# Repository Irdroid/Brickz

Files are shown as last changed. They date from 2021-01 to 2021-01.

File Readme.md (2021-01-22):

**Brickz Bluetooth Infrared Blaster / Transmitter by Irdroid**

**Introduction** 

Brickz is a Open Source Platform Independent Bluetooth Infrared Transmitter / Blaster that supports GNU Linux, MS Windows MAC OS X and Android. Brickz allows you to transmit Pronto HEX Infrared codes via its built-in infrared LEDs or via a IR extender cable that connect to brickz via a 3.5mm Mono Audio jack. The unit is capable of connecting to the host PC via USB as well as Bluetooth. It shows up as a bluetooth serial port, when that interface option is used, or as a USB Serial Device if the USB Interface connection is used.(https://irdroid.eu/product/brickz/)
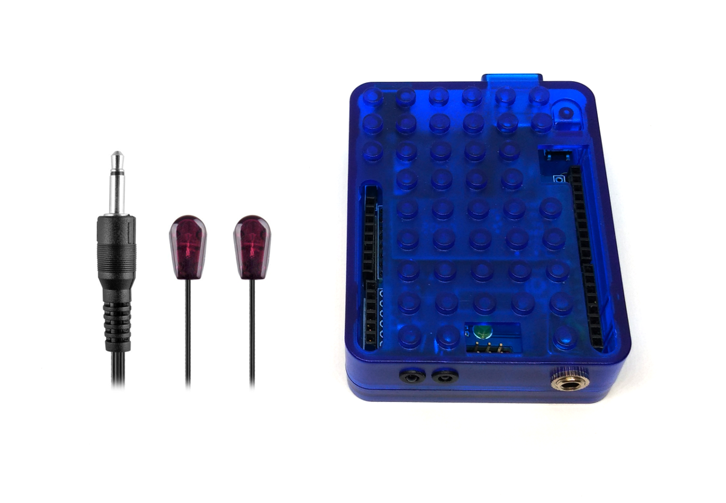
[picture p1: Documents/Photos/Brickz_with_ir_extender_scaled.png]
Brickz


**Features:**
- Bluetooth communication with the HOST SYSTEM / MCU
- USB Connection with the host System
- Built-in high power infrared leds
- Optional infrared transmitter extender
- Infrared operates at 940nm wavelength

**Example Application:**
- Digital signage infrared remote control & automation
- Home Automation & remote control
- Media remote control & automation systems

**How It works?**

Brickz listens for PRONTO HEX infrared codes via USB<>Serial or Bluetooht, simply connect to brickz via Bluetooth or USB open a terminal and type in the PRONTO code and hit enter, the command will be blasted through Brickz.If you are using Brickz with Android you can check out the example open source application that comes with brickz for sending pronto HEX codes. For detailed examples and usage, please refer to Brickz User's Manual, available in this repo.

On MAC OS X and GNU Linux once you pair with Brickz you can send PRONTO HEX codes directly from the console or via a bash script. This gives you the ability to make automation using script or controlling infrared devices directly from the console, from a script or scheduling infrared commands via cron. On MS Windows you can use any terminal application such as realterm or putty to send infrared commands with Brickz, or use the SerialSend.exe command line utility to send Infrared Codes to Brickz.

**Product website and Documentation**

- [Brickz official product Website](https://irdroid.eu/product/brickz)
- Documentation, Schematics, Production files and Software for Brickz can be found in this repository.

**Purchase sample unit**

- [Brickz official product Website](https://irdroid.eu/product/brickz)
- [Tindie](https://www.tindie.com/products/irdroid/brickz-bluetooth-infrared-transmitter/)

**You want to help with the development?**

- Write us an email to info@irdroid.com

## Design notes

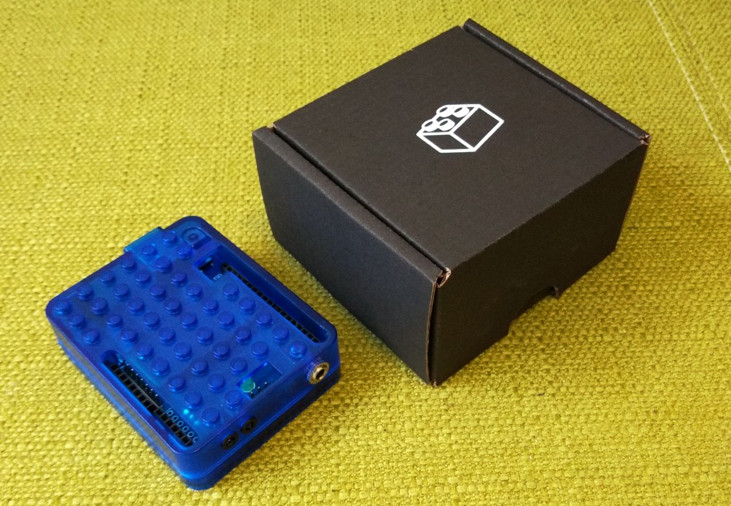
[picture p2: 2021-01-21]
Documents/Photos/Brickz_with_box_scaled.png

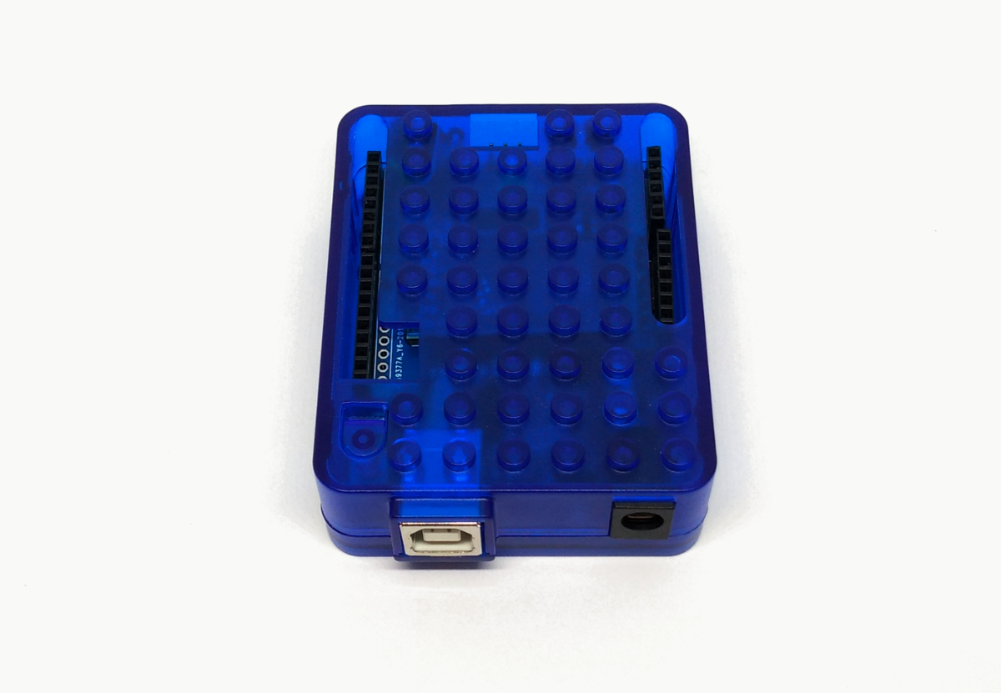
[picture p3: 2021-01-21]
Documents/Photos/Brickz_back_interfaces.png

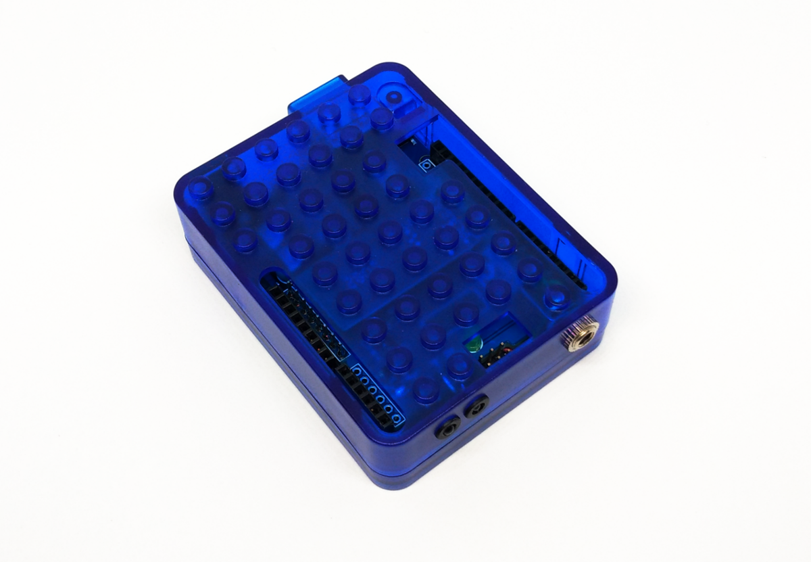
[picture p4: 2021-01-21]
Documents/Photos/Brickz_front_interfaces.png

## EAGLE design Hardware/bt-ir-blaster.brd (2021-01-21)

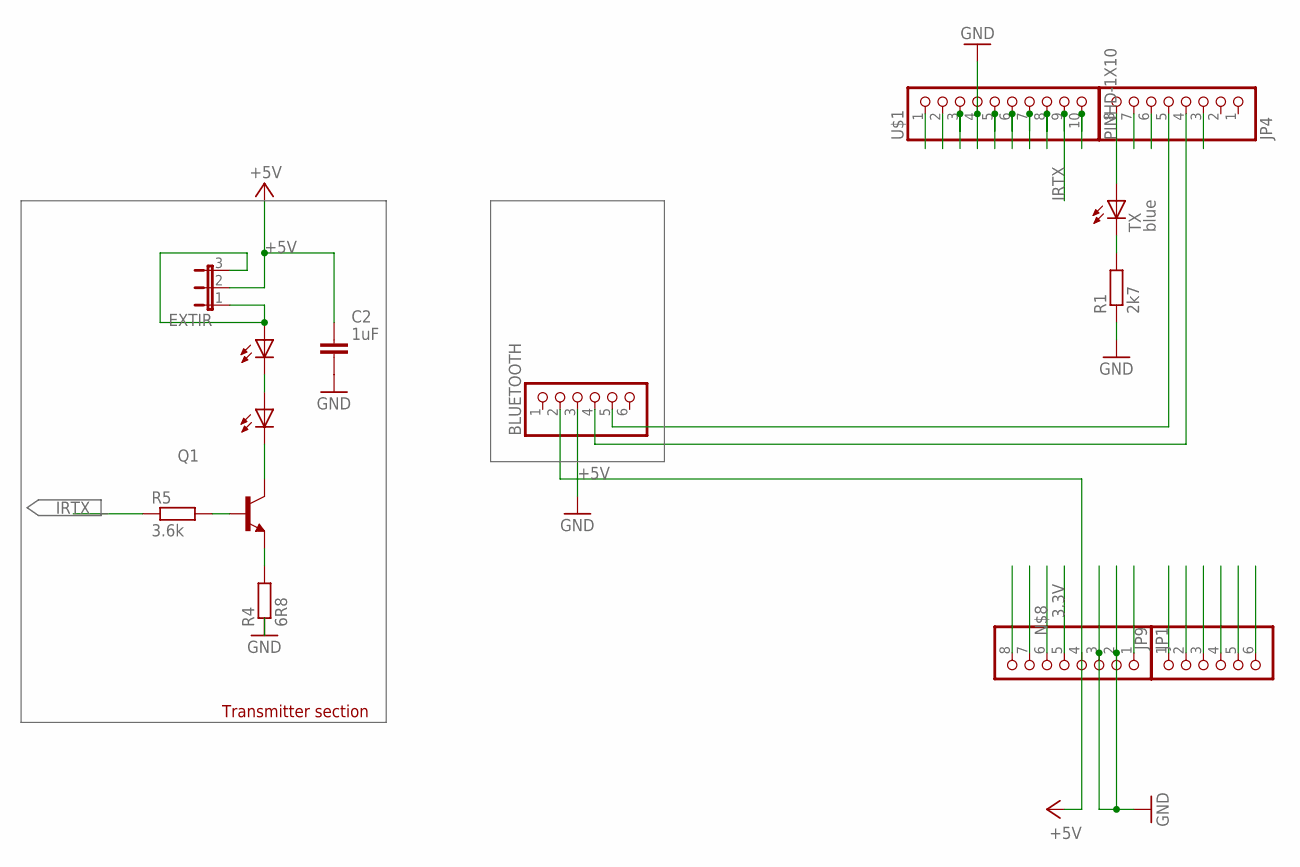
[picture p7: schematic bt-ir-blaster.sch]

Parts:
BLUETOOTH: PINHD-1X6; 1X06
C2: 1uF; C603@1
EXTIR: JP2E; JP2
JP1, JP4: PINHD-1X8BIG; 1X08-BIG
JP9: PINHD-1X6B; 1X06-BIG
Q1: TRANSISTOR_BJT_NPN-SOT-23-BCE; SOT-23
R1: 2k7; R0805
R4: 6R8; R1206
R5: 3.6k; R0603
TX: blue; LED3MM
U$1: PINHD-1X10; 1X10-BIG
U$5, U$7: IRLED5MM; IRLED_HOLDER

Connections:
3.3V: JP1.5
+5V: BLUETOOTH.2, C2.1, EXTIR.2, JP1.4
A: Q1.2 (C), U$5.K (C)
GND: BLUETOOTH.3, C2.2, JP1.2, JP1.3, R1.1, R4.1, U$1.4
IRTX: R5.1, U$1.9
K: Q1.3 (E), R4.2
unnamed: Q1.1 (B), R5.2
unnamed: U$5.A, U$7.K (C)
unnamed: R1.2, TX.K (C)
unnamed: EXTIR.1, EXTIR.3, U$7.A
unnamed: BLUETOOTH.4, JP4.4
unnamed: BLUETOOTH.5, JP4.5
unnamed: JP4.8, TX.A

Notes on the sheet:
Transmitter section

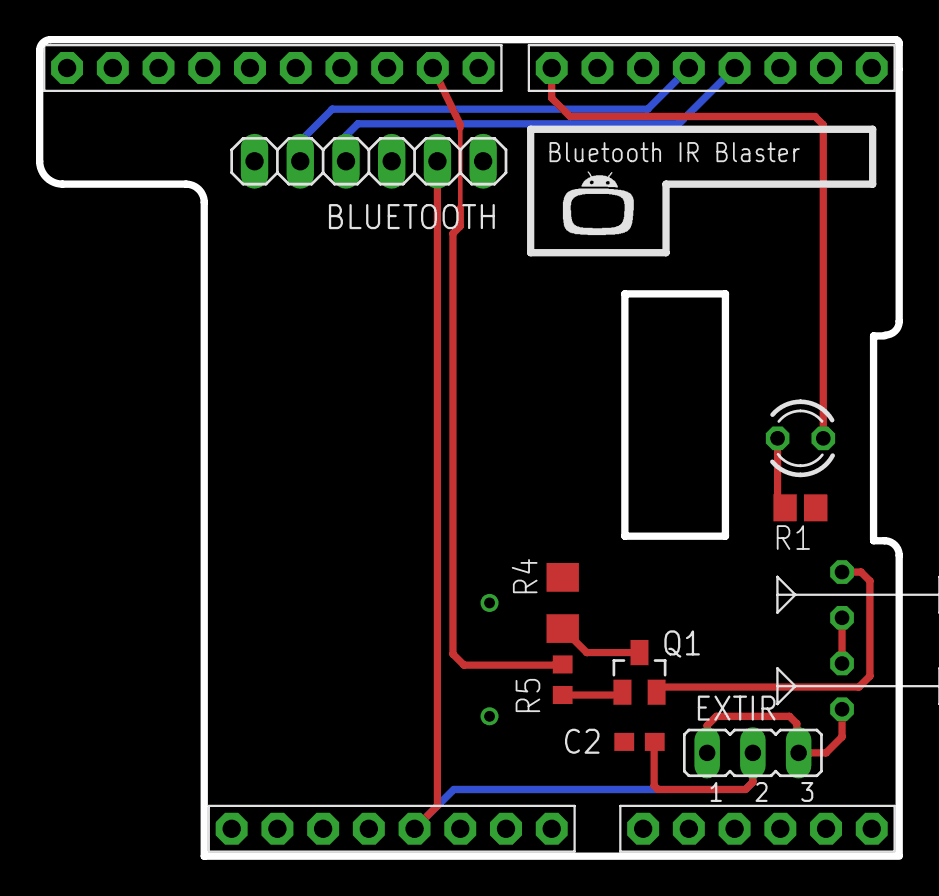
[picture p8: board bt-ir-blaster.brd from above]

Board: 2 copper layers, 47.8 x 45.4 mm, 15 parts (0 on the bottom side), 12 nets.

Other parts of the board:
U$44: IRDROIDLOGO

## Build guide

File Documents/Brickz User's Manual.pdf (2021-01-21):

1

# User’s Manual

## Brickz Bluetooth Infrared Blaster

© Brickz by Irdroid

# Introduction

Brickz Bluetooth IR Blaster is Platform Independent Bluetooth Infrared Transmitter / Blaster , compatible with GNU Linux, MS Windows, MAC OS X and Android. The module features Bluetooth SPP (Serial Port Protocol ) and USB interface connection with the host system.The module design is based on powerful MCU, which offers great customization of the firmware due to its support with the Arduino Development environment. Brickz has two powerful Infrared Leds and a 3.1mm mono jack for connecting Infrared Extender cable. The code format that module uses is the widely used PRONTO HEX Infrared code format, which provides flexibility and makes it universal.

## Module Features:

- Bluetooth communication with the HOST SYSTEM / MCU
- USB Connection with the host System
- Built-in high power infrared leds
- Optional infrared transmitter extender
- Infrared operates at 940nm wavelength

## Example Application

- Digital signage infrared remote control & automation
- Home Automation & remote control
- Media remote control & automation systems

## Device Setup & Pairing

Brickz is shipped with a USB-A to USB-B cable which by default can power Brickz by any USB port available nearby (Including USB Chargers, Computer USB Ports etc). Once you connect it via USB, the unit will bootup and it will be listening for new Infrared codes both from its USB and Bluetooth communication interfaces.

Powering the device is also possible via a standard 2.1mm DC Power Adapter with rating 9-12V DC. In case you use a DC Adapter then you dont need the USB connection for power.

If you plan to hide brickz behind a TV or any other object, you can use the infrared extender cable that comes with the package. The Infrared Extender head has a double sided 3M skotch tape which will allow you to fix the IR head next to the TV or near your target remote control device.

The Brickz bluetooth IR blaster uses a standard bluetooth SPP serial communication protocol, which enumerates on the host system as a serial port. To connect to Brickz over bluetooth enable the bluetooth connection on your computer / smartphone and open bluetooth settings. Wait for the device discovery to complete and select the Brickz bluetooth name from the list of the discovered devices. You will be asked to enter a bluetooth pairing code - the pairing code is 1234.

Once the pairing is complete and the connection established you will be able to communicate with the device by rfcomm or via the newly created serial port on the host system (See examples below).

## Android

Brickz for android example application is open source software and its source code and binary releases (APKs) can be downloaded from Irdroid’s GitHub repository dedicated for the Brickz Project (links at the end of the Manual). The application provide means for connecting to brickz and sending predefined PRONTO HEX codes. These codes are freely available and can be downloaded online from the remote-central infrared database or any other infrared database on the internet. By default the application is hardcoded with Samsung TV Discreate PRONTO HEX codes, fro turning TV on and OFF etc.

## MS Windows

In MS Windows you can pair and connect to Brickz via bluetooth and once the pairing procedure is completed a new virtual serial port will show up on your system (You can identify the serial port name by visting Control Panel-> Device Manages -> System). Once you identify the serial port name, you can use serial terminal applications such as RealTerm, Putty or any other serial terminal to connect to Brickz’s serial port and send PRONTO HEX Codes via serial

The default serial settings are 9600 8 n 1 . These settings need to be entered into the serial terminal application that you use.

## GNU Linux

In Linux, you can pair and connect to Brickz and use rfcomm in order to enumerate Brickz on your system as a serial port and be able to use any serial terminal application such as gtkterm in order to send pronto ir codes to brickz.

1. Use the bluetoothctl utility to scan for Brickz and obtain its bluetooth mac address so that you can use it to connect via rfcomm :
a. first enter bluetoothctl
b. scan on c. after the scan completes you will see a list of available devices with their MAC addresses , identify Brickz by name and copy its MAC address which will be used in the next step
2. Use the following command to bind Brickz to /dev/rfcomm0 device on your system:
a. frcomm bind brickz_bluetooth_mac_address.
3. Once you complete the step above a new device will show up in /dev called /dev/rfcomm0
4. Use Serial Terminal application such as gtkterm to connect to /dev/rfcomm0 9600 8 n 1
5. After completion of the above step you can directly send Pronto HEX codes form the terminal ( At the end of this manual you will find links to the most popur PRONTO IR Databases available on the Internet)

## MAC OS X

In MAC OS X you have to go through the pairing procedure with Brickz.

1. Enable Bluetooth
2. Open Bluetooth Settimgs
3. Search for Brickz name in the list of available bluetooth devices
4. Pair / Enter Brickz default pairing code - 1234
5. Once Pairing is complete a new device will become available in your /dev folder
6. Open a terminal and type cd /dev ;ls
7. The new device file name should start with try.brickz….

At this point you can send infrared codes directly to Brickz directly from the terminal. Type :

echo -e -n "SEND YOUR PRONTO CODE\n" > /dev/tty.brickz…

And the it command will be sent to Brickz and executed.

## Links

- http://www.remotecentral.com/cgi-bin/codes/ remote central pronto hex ir codes database
- https://irdb.tk A website which allow you to generate ir codes in various format depending on the protocol
- https://irdroid.eu/product/Brickz - bricks website
- https://github.com/irdroid/Brickz - Source code & Documentation

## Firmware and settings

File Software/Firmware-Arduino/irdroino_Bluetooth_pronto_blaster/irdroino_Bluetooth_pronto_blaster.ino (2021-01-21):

/*
Send Pronto Hex via an IR LED connected to Arduino Pin D9.
 Make sure you do not send a blank (" ") as the last character.
 Send the following command over the serial line:
 
 # Sony12, device = 1, obc = 47
 SEND 0000 0067 0000 000d 0060 0018 0030 0018 0030 0018 0030 0018 0030 0018 0018 0018 0030 0018 0018 0018 0030 0018 0018 0018 0018 0018 0018 0018 0018 03de
 
 or
 
 # RC5, device = 11, obc = 64
 SEND 0000 0073 0000 000B 0040 0020 0020 0020 0020 0040 0040 0040 0020 0020 0040 0020 0020 0020 0020 0020 0020 0020 0020 0020 0020 0CC8
 
 Based on https://github.com/stephenong/Arduino-IR-Remote-Control-Player
 */


#include <avr/interrupt.h>
#include <stdio.h>
#include <avr/pgmspace.h>
#include <stdint.h>
#include <avr/io.h>
#define IR_PORT PORTB
#define IR_PIN PINB
#define IR_DDR DDRB
#define IR_BV _BV(1)
#define IR_OCR OCR1A
#define IR_TCCRnA TCCR1A
#define IR_TCCRnB TCCR1B
#define IR_TCNTn TCNT1
#define IR_TIFRn TIFR1
#define IR_TIMSKn TIMSK1
#define IR_TOIEn TOIE1
#define IR_ICRn ICR1
#define IR_OCRn OCR1A
#define IR_COMn0 COM1A0
#define IR_COMn1 COM1A1
#define PRONTO_IR_SOURCE 0 // Pronto code byte 0
#define PRONTO_FREQ_CODE 1 // Pronto code byte 1
#define PRONTO_SEQUENCE1_LENGTH 2 // Pronto code byte 2
#define PRONTO_SEQUENCE2_LENGTH 3 // Pronto code byte 3
#define PRONTO_CODE_START 4 // Pronto code byte 4
#include <SoftwareSerial.h> 
SoftwareSerial MyBlue(3, 4); // RX | TX 

static const uint16_t *ir_code = NULL;
static uint16_t ir_cycle_count = 0;
static uint32_t ir_total_cycle_count = 0;
static uint8_t ir_seq_index = 0;
static uint8_t ir_led_state = 0;
 int orangeLedPin =  7;

void ir_on()
{
  IR_TCCRnA |= (1<<IR_COMn1) + (1<<IR_COMn0);
  ir_led_state = 1;
}

void ir_off()
{
  IR_TCCRnA &= ((~(1<<IR_COMn1)) & (~(1<<IR_COMn0)) );
  ir_led_state = 0;
}

void ir_toggle()
{
  if (ir_led_state)
    ir_off();
  else
    ir_on();
}

void ir_start(uint16_t *code)
{
  ir_code = code;
  IR_PORT &= ~IR_BV; // Turn output off
  IR_DDR |= IR_BV; // Set it as output
  IR_TCCRnA = 0x00; // Reset the pwm
  IR_TCCRnB = 0x00;
  //printf_P(PSTR("FREQ CODE: %hd\r\n"), code[PRONTO_FREQ_CODE]);
  uint16_t top = ( (F_CPU/1000000.0) * code[PRONTO_FREQ_CODE] * 0.241246 ) - 1;
  //printf_P(PSTR("top: %hu\n\r"), top);
  IR_ICRn = top;
  IR_OCRn = top >> 1;
  IR_TCCRnA = (1<<WGM11);
  IR_TCCRnB = (1<<WGM13) | (1<<WGM12);
  IR_TCNTn = 0x0000;
  IR_TIFRn = 0x00;
  IR_TIMSKn = 1 << IR_TOIEn;
  ir_seq_index = PRONTO_CODE_START;
  ir_cycle_count = 0;
  ir_on();
  IR_TCCRnB |= (1<<CS10);
}

#define TOTAL_CYCLES 80000 // Turns off after this number of
// cycles. About 2 seconds
// FIXME: Turn off after having sent
ISR(TIMER1_OVF_vect) {
  uint16_t sequenceIndexEnd;
  uint16_t repeatSequenceIndexStart;
  ir_total_cycle_count++;
  ir_cycle_count++;

  if (ir_cycle_count== ir_code[ir_seq_index]) {
    ir_toggle();
    ir_cycle_count = 0;
    ir_seq_index++;
    sequenceIndexEnd = PRONTO_CODE_START +
      (ir_code[PRONTO_SEQUENCE1_LENGTH]<<1) +
      (ir_code[PRONTO_SEQUENCE2_LENGTH]<<1);

    repeatSequenceIndexStart = PRONTO_CODE_START +
      (ir_code[PRONTO_SEQUENCE1_LENGTH]<<1);

    if (ir_seq_index >= sequenceIndexEnd ) {
      ir_seq_index = repeatSequenceIndexStart;

      if(ir_total_cycle_count>TOTAL_CYCLES) {
        ir_off();
        TCCR1B &= ~(1<<CS10);
      }
    }
  }
}

void ir_stop()
{
  IR_TCCRnA = 0x00; // Reset the pwm
  IR_TCCRnB = 0x00;
}

const uint16_t inputLength = 512;

void setup() {
 // Serial.begin(9600);
 Serial.begin(9600); 
 MyBlue.begin(9600); 
  Serial.println("READY");
 // MyBlue.println("READY");

pinMode(orangeLedPin, OUTPUT);  
}

void loop()
{
  if ( Serial.available() > 0 )
  {
    static char input[inputLength];
    static uint16_t i;
    char c = Serial.read();

    if ( c != '\r' && c != '\n' && i < inputLength-1)
      input[i++] = c;

    else
    {
      input[i] = '\0';
      i = 0;

      uint16_t array[80];
      uint16_t j = 0;

      if ( !strncmp(input, "SEND", 4) )
      {
        char* p = input+4;

        while ( (p = strchr(p, ' ')) != NULL )
          array[j++] = strtol(p, &p, 16);

        ir_start(array);
        Serial.print("SENT ");
        for ( uint8_t i = 0; i < j; i++ )
        {
          Serial.print ("0x");
          Serial.print (array[i], HEX);
          Serial.print(" ");
        }

digitalWrite(orangeLedPin, HIGH); 
    delay(200);
    digitalWrite(orangeLedPin, LOW); 
    delay(200);  
        Serial.println();
      }
    }
  }
  if ( MyBlue.available() > 0 )
  {
    static char input[inputLength];
    static uint16_t i;
    char c = MyBlue.read();

    if ( c != '\r' && c != '\n' && i < inputLength-1)
      input[i++] = c;

    else
    {
      input[i] = '\0';
      i = 0;

      uint16_t array[80];
      uint16_t j = 0;

      if ( !strncmp(input, "SEND", 4) )
      {
        char* p = input+4;

        while ( (p = strchr(p, ' ')) != NULL )
          array[j++] = strtol(p, &p, 16);

        ir_start(array);
    //    MyBlue.print("SENT ");
    //    for ( uint8_t i = 0; i < j; i++ )
    //    {
     //     MyBlue.print ("0x");
     //     MyBlue.print (array[i], HEX);
      //    MyBlue.print(" ");
     //   }

digitalWrite(orangeLedPin, HIGH); 
    delay(200);
    digitalWrite(orangeLedPin, LOW); 
    delay(200);  
        Serial.println();
      }
    }
  }
}
